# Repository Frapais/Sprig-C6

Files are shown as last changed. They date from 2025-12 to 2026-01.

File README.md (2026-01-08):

# Sprig-C6 ESP32 Development Board 
**Sprig-C6** is the latest addition to the [SprigStack ecosystem](https://sprig-labs.com/) of boards designed to simplify the development of DIY IoT devices. Sprig-C6 is build around the [ESP32-C6](https://www.espressif.com/en/products/socs/esp32-c6) microcontroller which supports WiFi6, BLE, as well as Zigbee, Matter, and Thread. Creating a Home Assistant device using the Sprig is as simple as it gets: 
1. Plug it to a PC via a USB-C cable while pressing the BOOT button (required only the first time).
2. Flash the firmware using the ESPHome plugin.
3. Copy the provided `.yaml` [configuration](Home%20Assistant%20Setup/c6-config.yaml) onto your ESPHome's `.yaml`

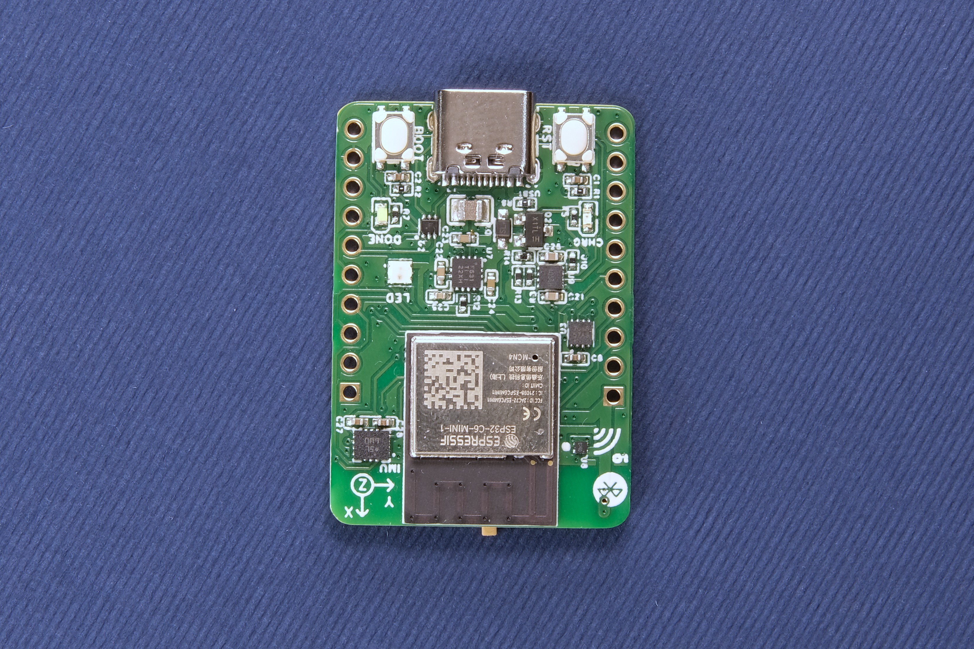
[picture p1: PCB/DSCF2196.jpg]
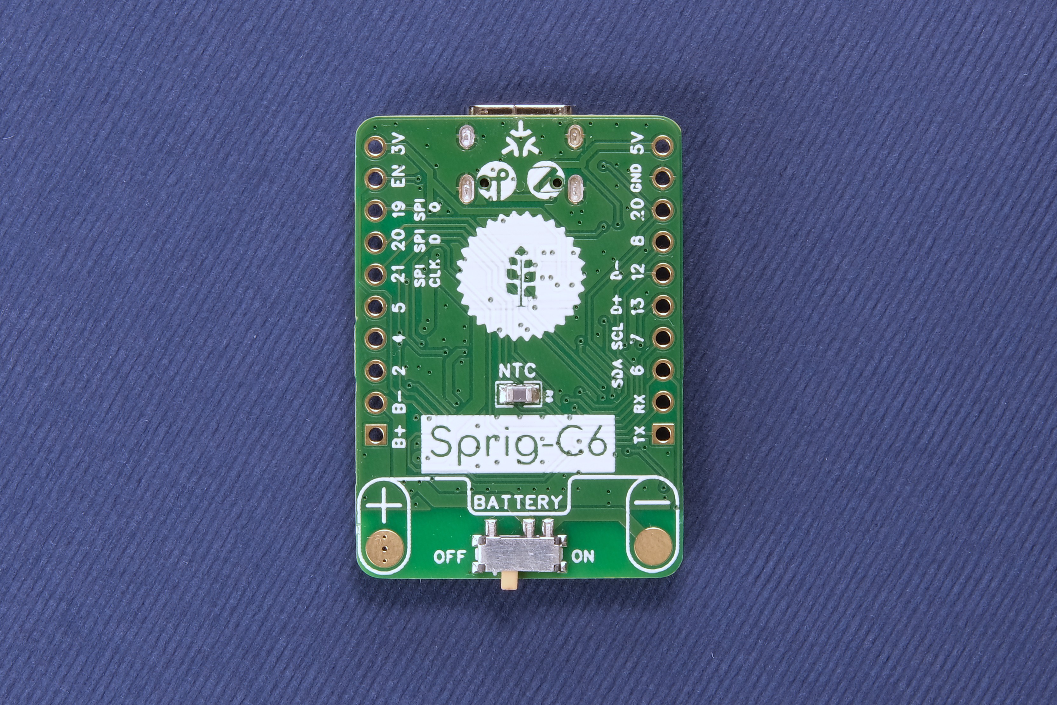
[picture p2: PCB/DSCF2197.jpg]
|  |  |
|---|---|
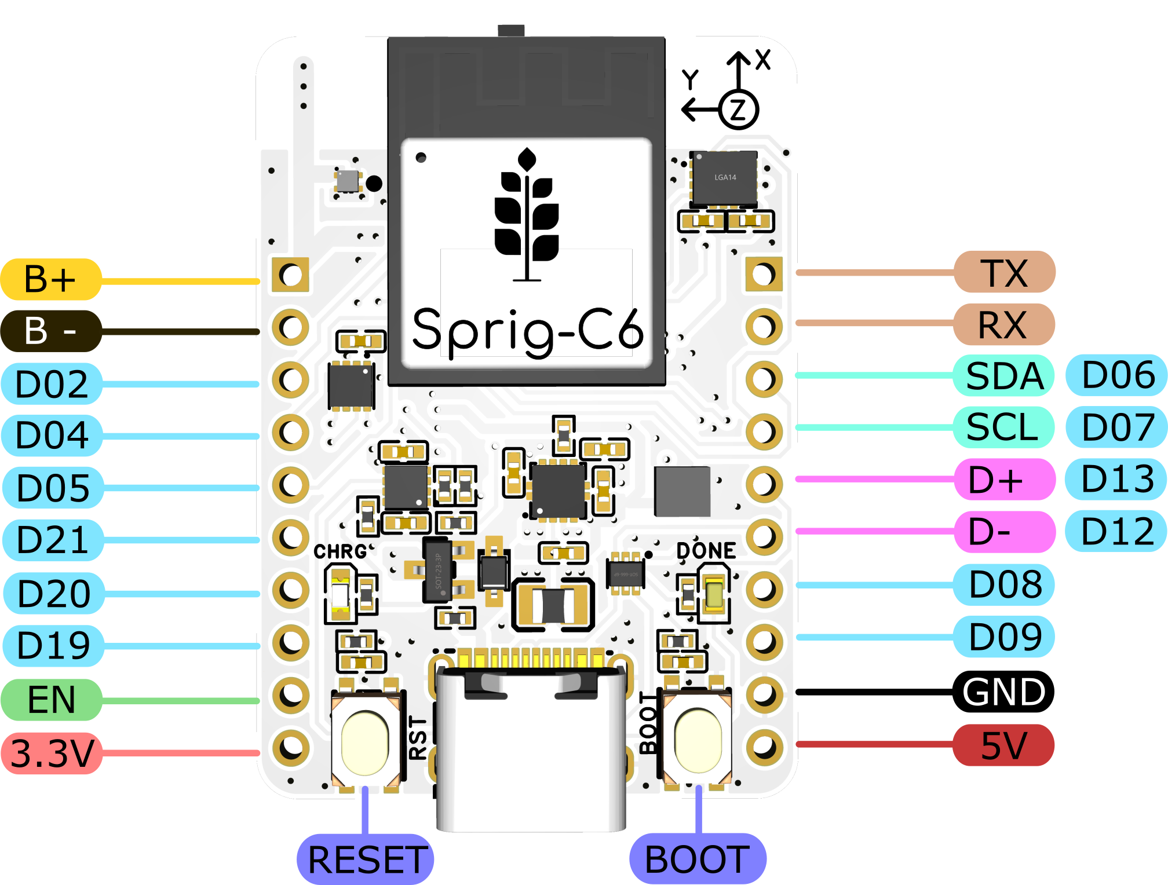
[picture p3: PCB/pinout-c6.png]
Pinout
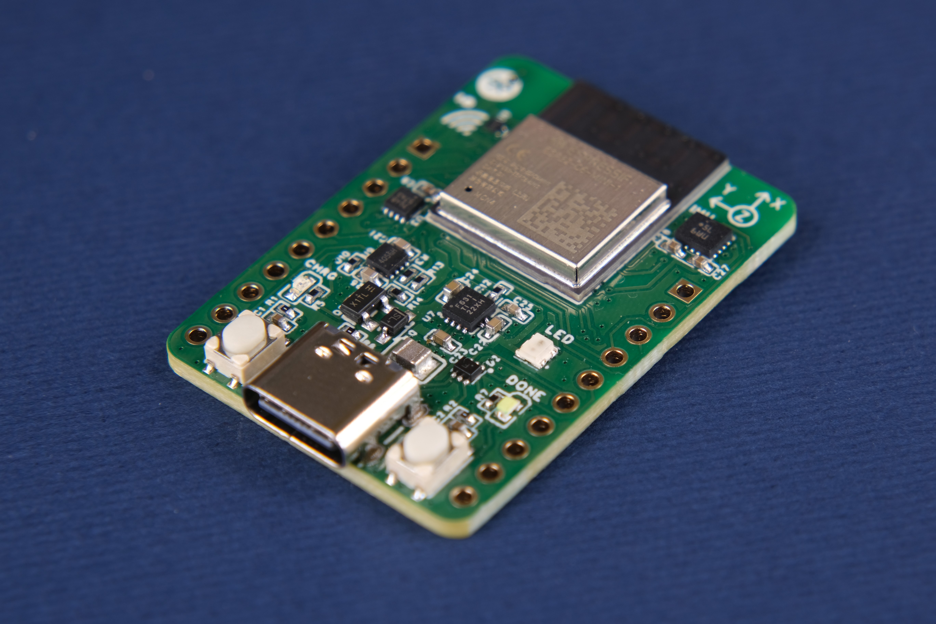
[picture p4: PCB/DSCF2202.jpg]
|  |  |

## Description
### Hardware
#### Main Features
* Li-ion/Li-po battery charging & protection ICs integrated with battery temperature monitoring.
* Accurate battery capacity measurement IC, accessible via I2C on pins 6 and 7.
* Neopixel RGB LED for advanced custom indications.
* BMI260 Accelerometer & Magnetometer.
* USB Type-C port for charging and uploading firmware.
* RESET and BOOT pushbuttons.
* "Charging" and "Done charging" states indicated by 2 LEDs.
* ON-OFF Switch on the battery terminals.
* Breadboard-compatible pin headers breaking out all the pins of ESP32-C6, as well as the USB, battery, and regulated 3.3V.

#### I2C Pins of the Sprig-C3 board
| Function | Pin No |
|---|---|
| SDA | 6 |
| SCL | 7 |

### Tests
* Battery over-discharge cutoff: 2.8V
* Battery end-of-charge voltage: 4.1V
* Battery thermal cutoff: ~70°C
* Max Charging Current: 500mA
* Regulated 3.3V noise: 10mV
* Maximum total power draw: 105mA
* Average power draw (awake WiFi mode): 32mA

| 3.3V noise @ 5V input & 500mA load: ~10mV | Battery over-discharge event | Battery connection event |
|---|---|---|
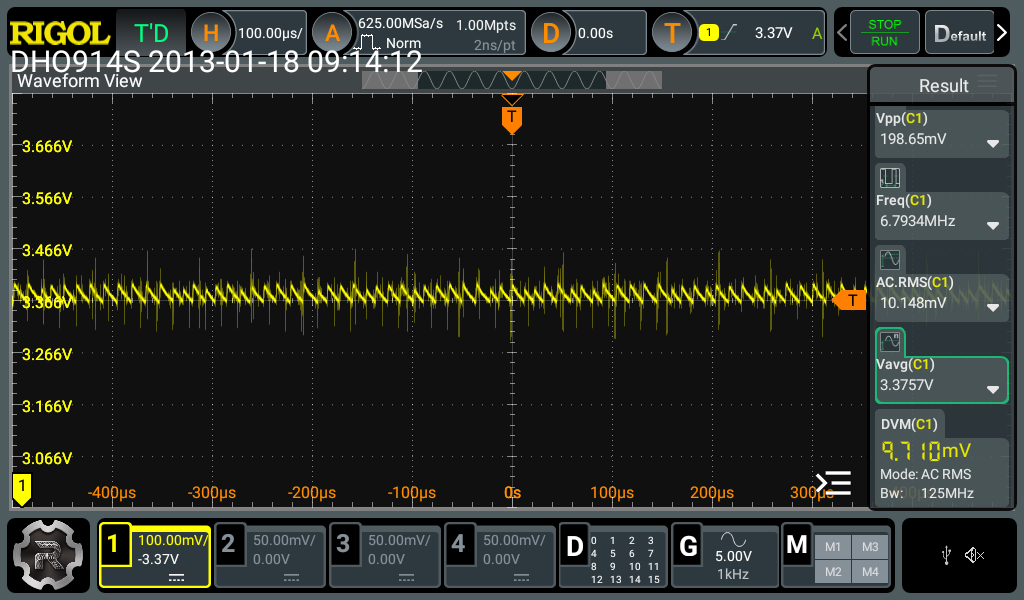
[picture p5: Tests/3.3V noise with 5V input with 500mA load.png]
Idle Power Consumption
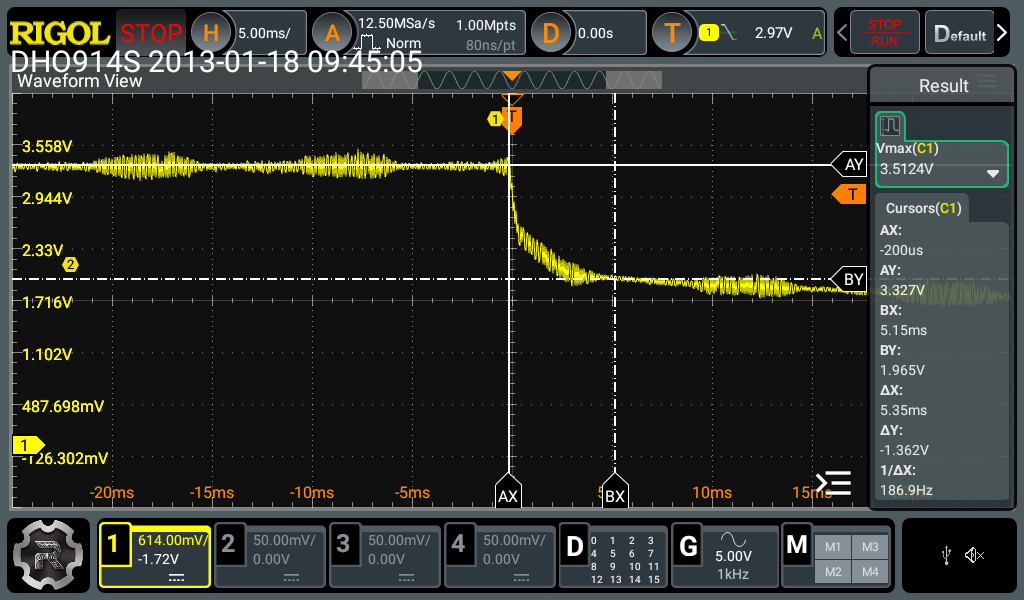
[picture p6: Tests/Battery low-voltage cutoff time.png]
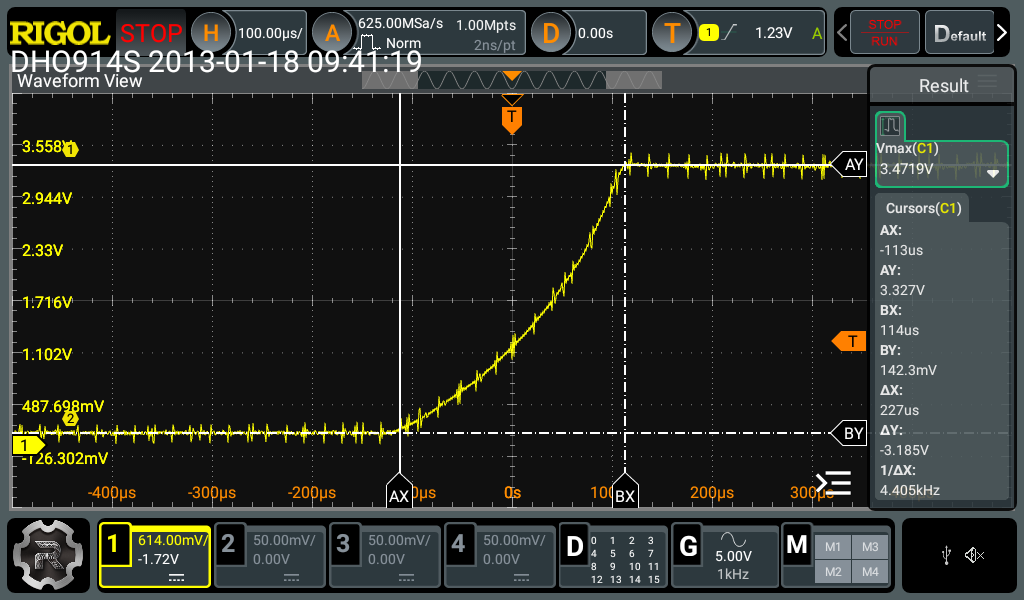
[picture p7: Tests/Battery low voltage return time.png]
|  |  |  |

### Initial Home Assistant setup
#### Requirements:
* Access to Home Assistant Dashboard
* Installed ESPHome plugin

#### Setup process:
1. Connect the Sprig-C6 board on the computer running Home Assistant, while pressing the BOOT button (required only the first time).
2. Open ESPHome, and add a new device as shown [here](https://esphome.io/guides/getting_started_hassio#dashboard-interface).
3. Select "Connect" to upload the initialization firmware on the board, and select the correct port from the popup window. (It usually shows up as a "USB JTAG" device).
4. Wait for the upload to finish, and restart the Sprig-C3. Now, every time you power on the device, it should connect to your WiFi automatically.
5. Last step, is to go to your Home Assistant settings, and Configure your newly discovered device (assuming it is powered on and visible on the network).

#### Video Tutorial: [Fist Home Assistant Setup](https://youtu.be/UaIIV4CaRA4)

### Battery Capacity Measurement
The Sprig-C6 board features the MAX17048 battery capacity measurement IC connected to the respective I2C pins. In the `c6-config.yaml` provided [here](Home%20Assistant%20Setup/c6-config.yaml), there is a sample code for proper communication with the ic. No further setup required.

## Availability
You can get the assembled boards in my [Tindie](https://www.tindie.com/products/34523/), or my [official website](https://sprig-labs.com/) stores.



## Certifications
This project is certified by the [Open Source Hardware Association (OSHWA)](https://certification.oshwa.org/gr000011.html)

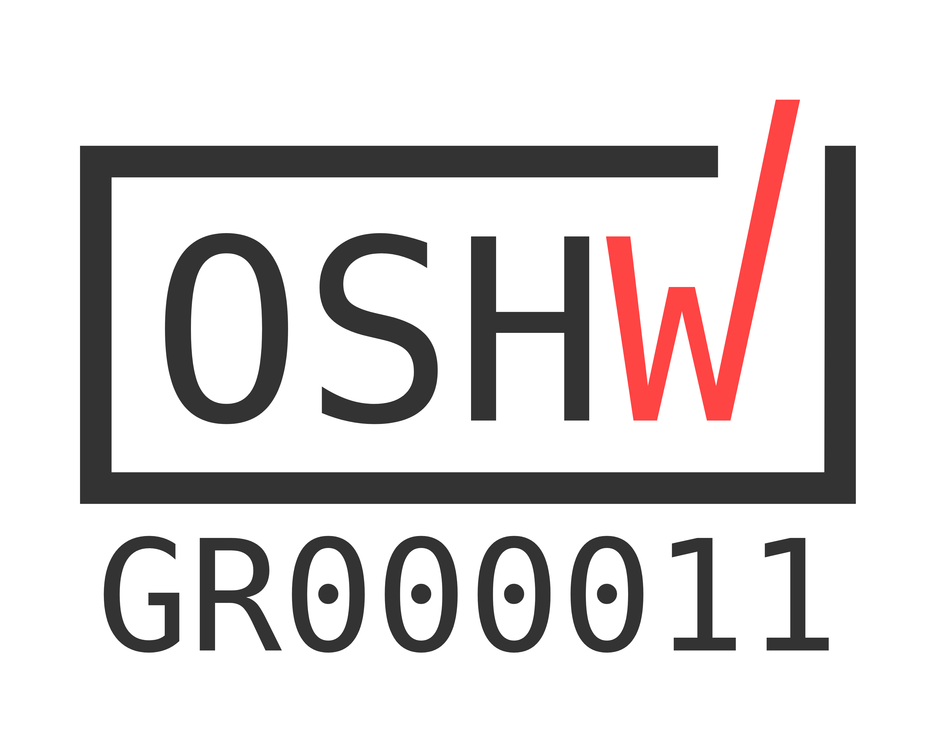
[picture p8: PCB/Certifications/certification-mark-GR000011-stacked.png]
Open Source Hardware Association Certification


## Support
If you find this project useful, please consider supporting me on any of the following platforms:
* PayPal:

  <a href="https://www.paypal.com/paypalme/kostasparaskevas">
    
* Buy Me a Coffe:

  <a href="https://www.buymeacoffee.com/spriglabs" target="_blank">Buy Me A Coffee</a>
* Instagram:
  [@sprig_labs](https://www.instagram.com/sprig_labs/)
* YouTube:
  [@sprig_labs](https://www.youtube.com/@sprig_labs)

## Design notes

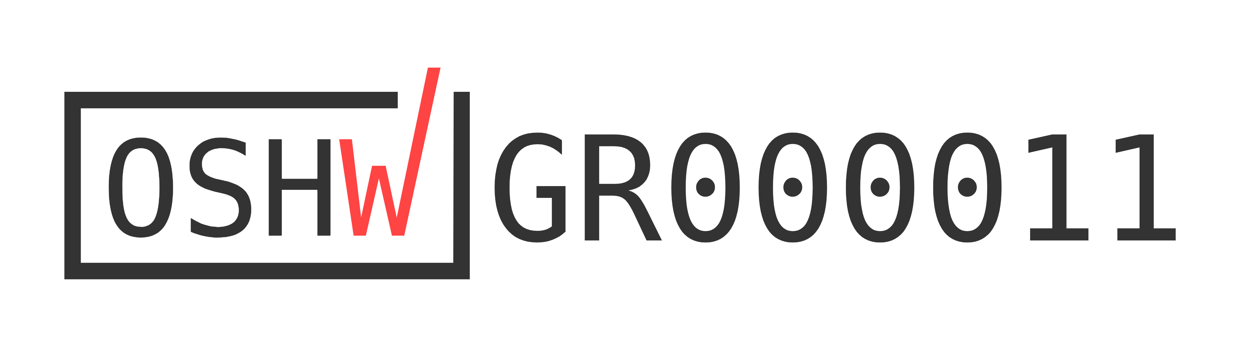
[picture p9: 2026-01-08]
PCB/Certifications/certification-mark-GR000011-wide.png

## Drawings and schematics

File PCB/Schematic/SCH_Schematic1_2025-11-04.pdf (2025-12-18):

IO21 27 IO22 28 IO23 29 RXD0 30 TXD0 31 NC 32 NC 33 NC 34 NC 35 GND 36 GND 37 GND 38 GND 39 GND 40 GND 41 GND 42 GND 43 GND 44 GND 45 GND 46 GND 47 GND 48 GND 49 GND 50 GND 51 GND 52 GND 53

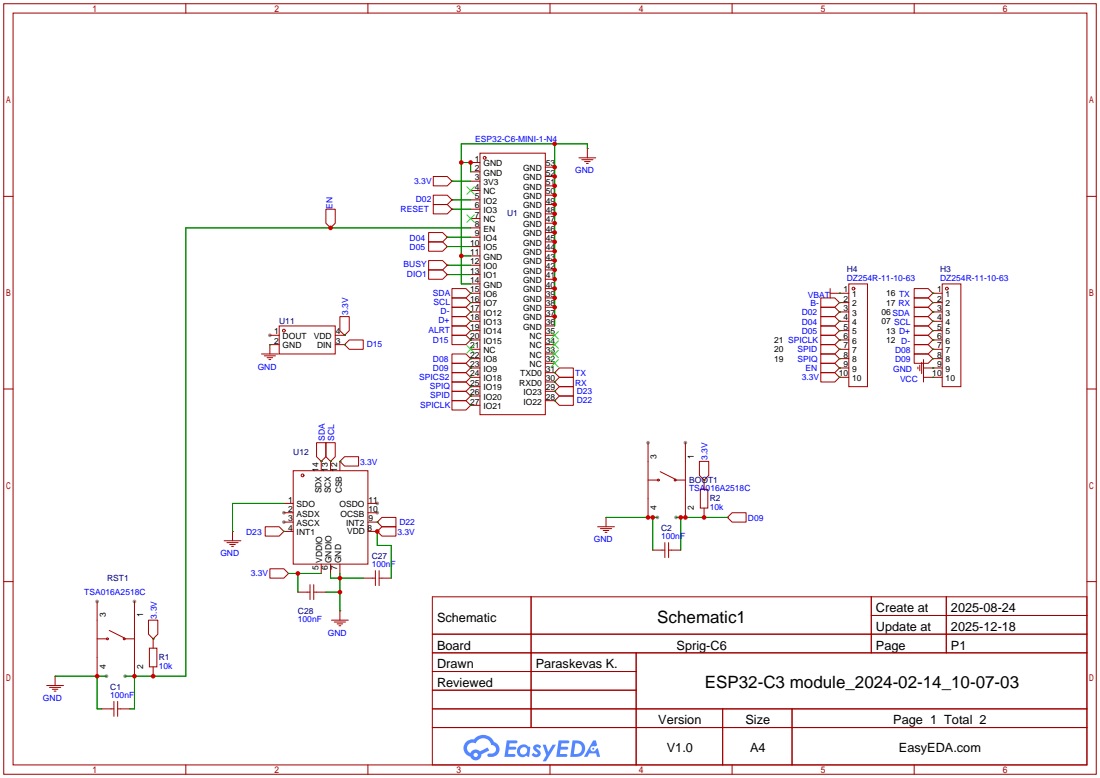
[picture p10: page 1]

OCSB 10 OSDO 11 CSB ¹²

Schematic | Schematic1 | Create at | 2025-08-24

Update at | 2025-12-18

Board | Sprig-C6 | Page | P1
Drawn | Paraskevas K. | ESP32-C3 module_2024-02-14_10-07-03
Reviewed

Version | Size | Page 1 Total 2
V1.0 | A4 | EasyEDA.com

Voltage Regulator | LiPo charger

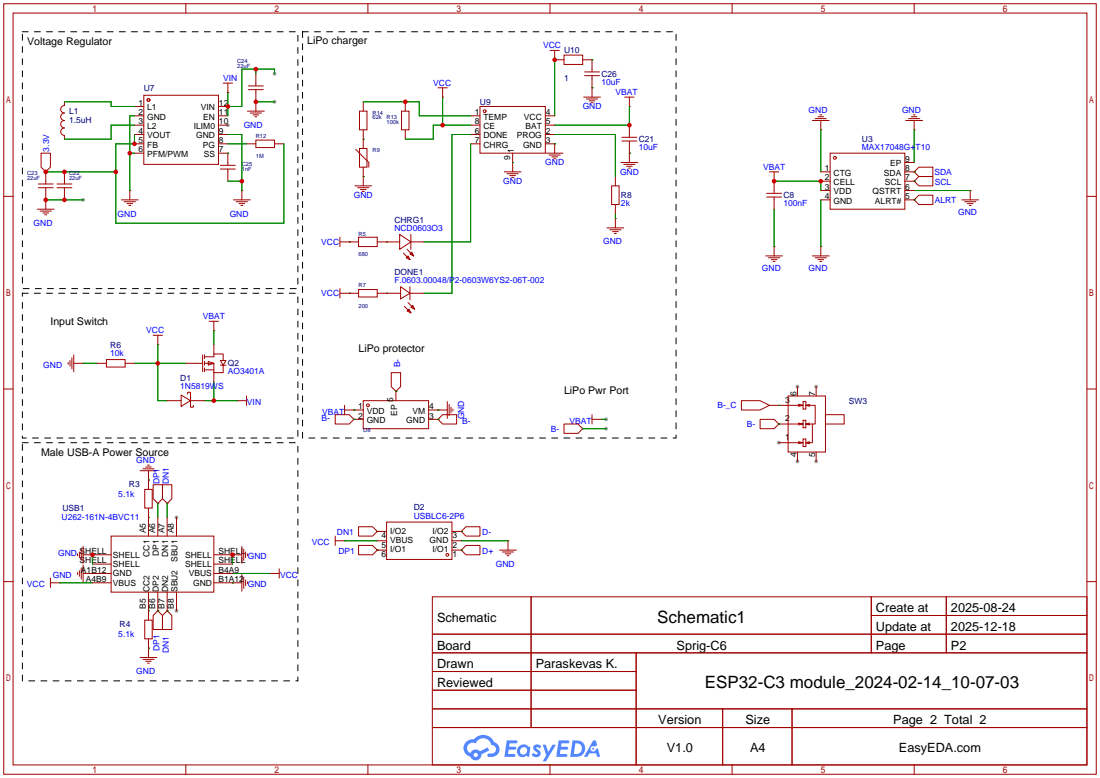
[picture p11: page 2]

Male USB-A Power Source

Schematic | Schematic1 | Create at | 2025-08-24

Update at | 2025-12-18

Board | Sprig-C6 | Page | P2
Drawn | Paraskevas K. | ESP32-C3 module_2024-02-14_10-07-03
Reviewed

Version | Size | Page 2 Total 2
V1.0 | A4 | EasyEDA.com

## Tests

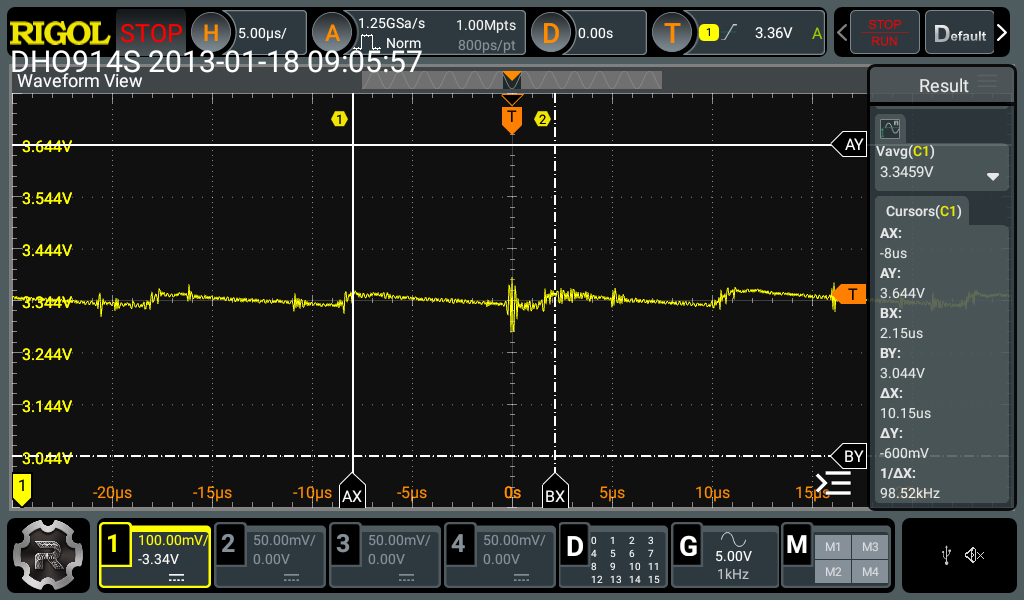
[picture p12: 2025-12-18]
Tests/3.3V Switching frequency.png

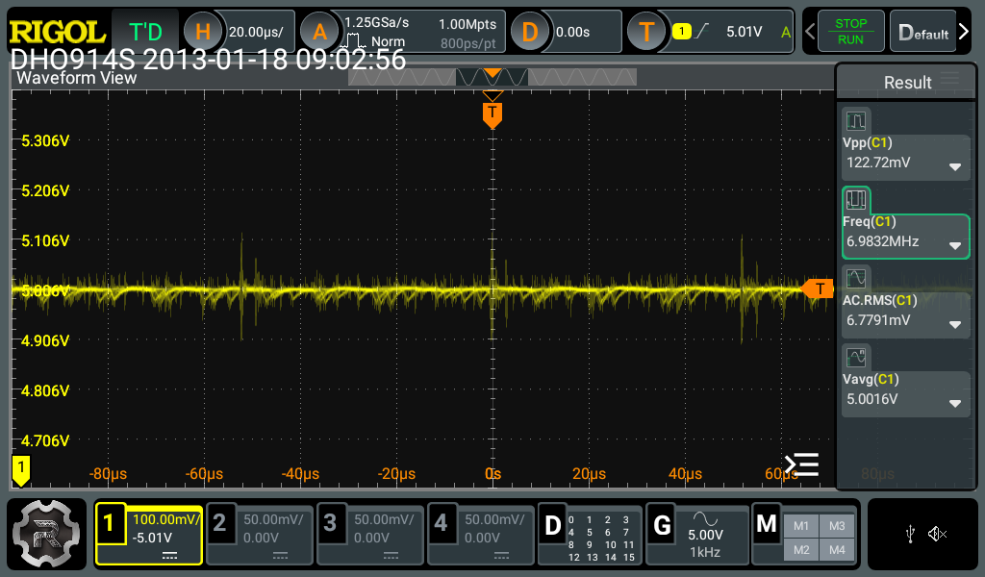
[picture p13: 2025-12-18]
Tests/input noise0.png

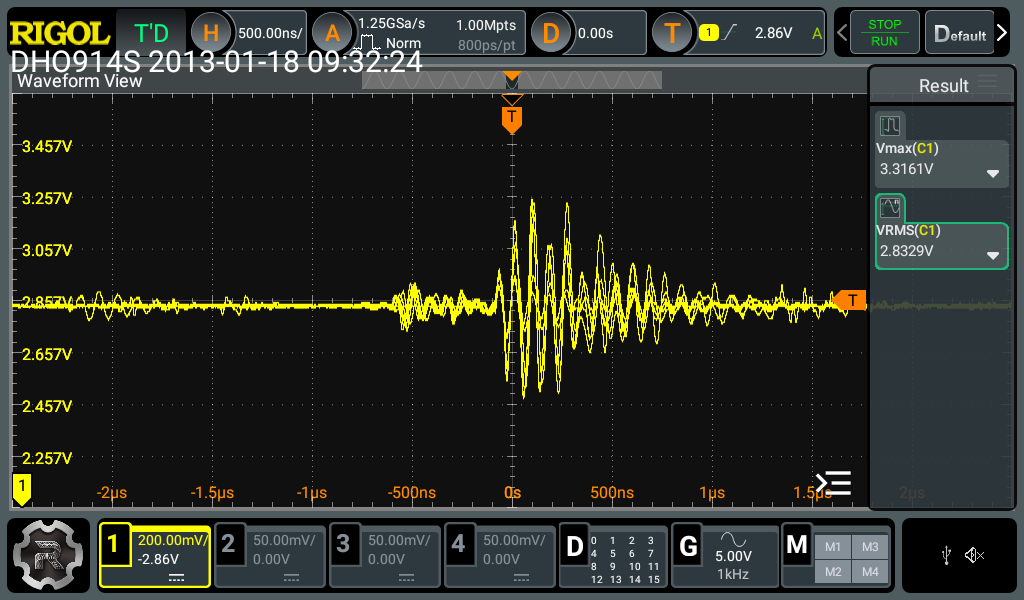
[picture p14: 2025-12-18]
Tests/Under-voltage cutoff threshold.png

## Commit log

2025-12-18 Uploaded all the project files
    Uploaded PCB and Schematic design files, as well as the Home Assistant configuration yaml, and the pinout of the board.
    [1_MC & Peripherals.schdoc, 1_P1.schdoc, 2_P2.schdoc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]
2025-12-18 Revise README for Sprig-C6 development board
    Updated README to reflect changes from Sprig-C3 to Sprig-C6, including new features, setup instructions, and battery capacity measurement details.
2025-12-18 Improve README with configuration links and corrections
    Updated README.md to include links to configuration files and corrected ESP32 model references.
2026-01-08 Fix links and add I2C pin details in README
    Updated links and added I2C pin information for the Sprig-C6 board.
